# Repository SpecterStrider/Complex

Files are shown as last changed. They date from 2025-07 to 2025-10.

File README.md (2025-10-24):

# Project COMPLEX
Complex is a 36-key ergonomic split keyboard inspired by  

Corne by foostan and  
https://github.com/foostan/crkbd/tree/main

Tempest by thrly  
https://github.com/thrly/tempest

## TO DO List
- [ ] Impedance match USB
- [ ] Right Side PCB
- [ ] include Case and 3d files
- [ ] Rebase from kiCAD to Fusion ECAD
- [ ] Begin QMK firmware
- [ ] define COMPLEX.cpp in QMK environment
- [ ] create Keyamp

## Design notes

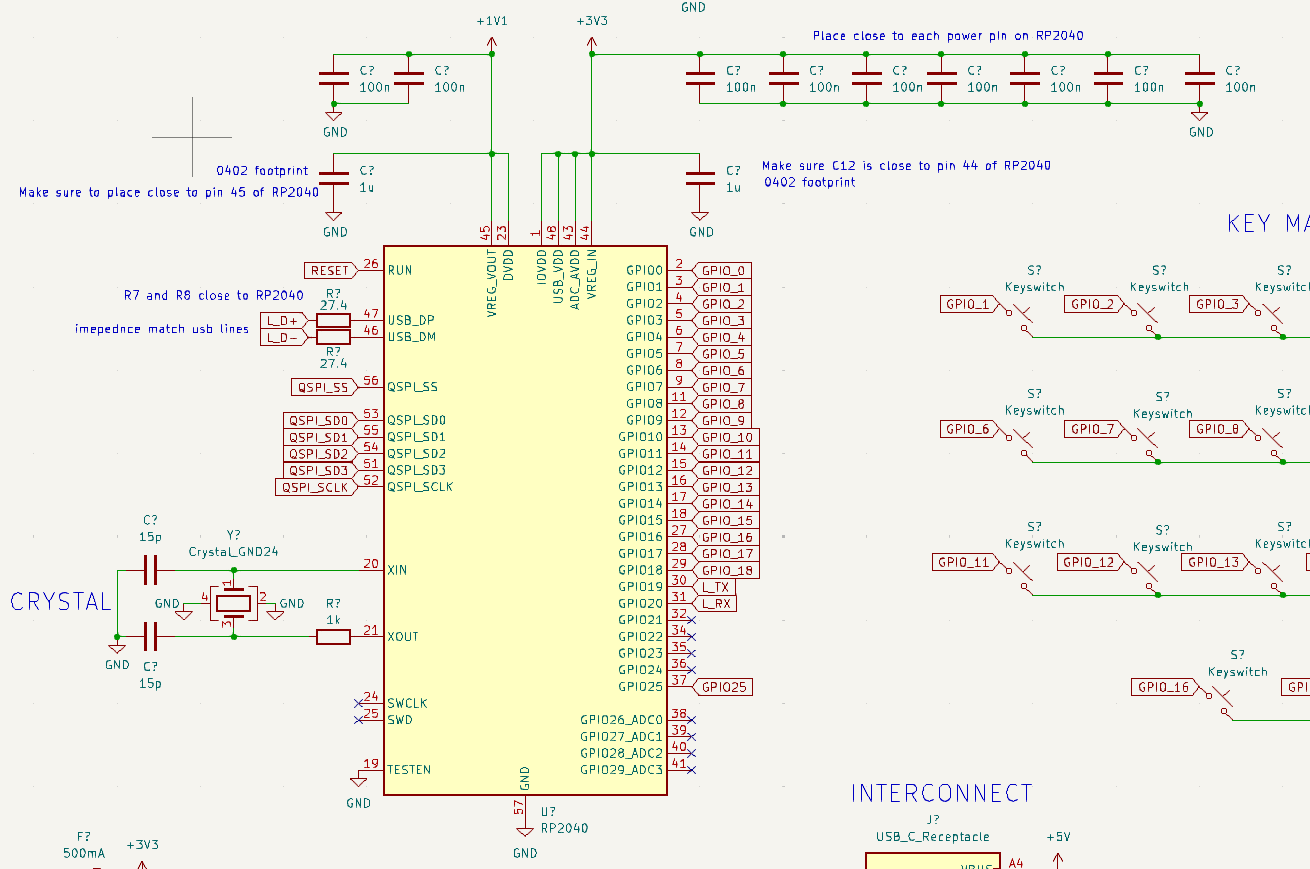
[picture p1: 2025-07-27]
Docs/MCU.png

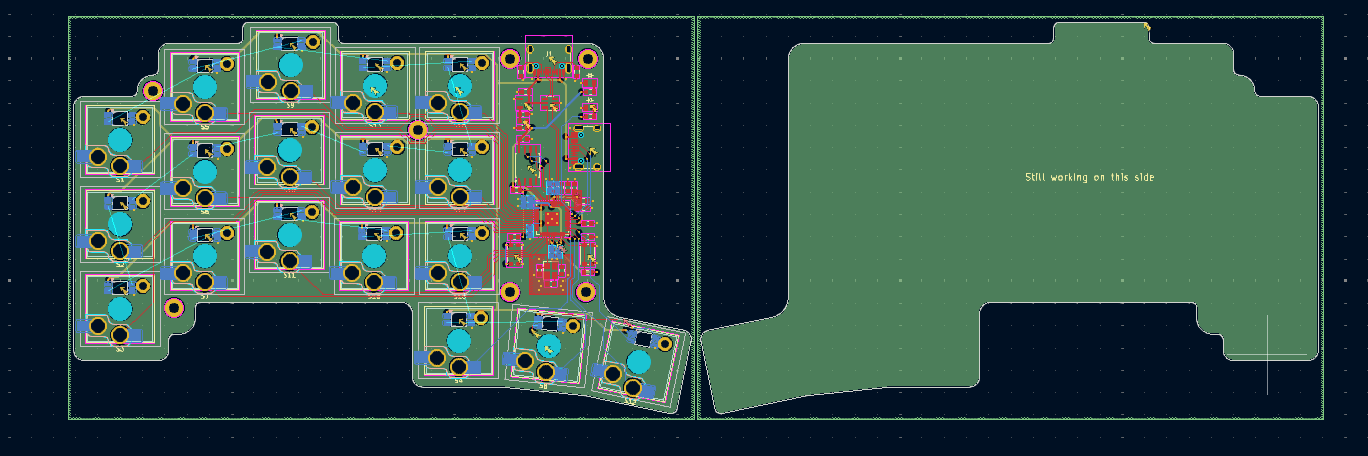
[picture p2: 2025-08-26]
Docs/PCB.png

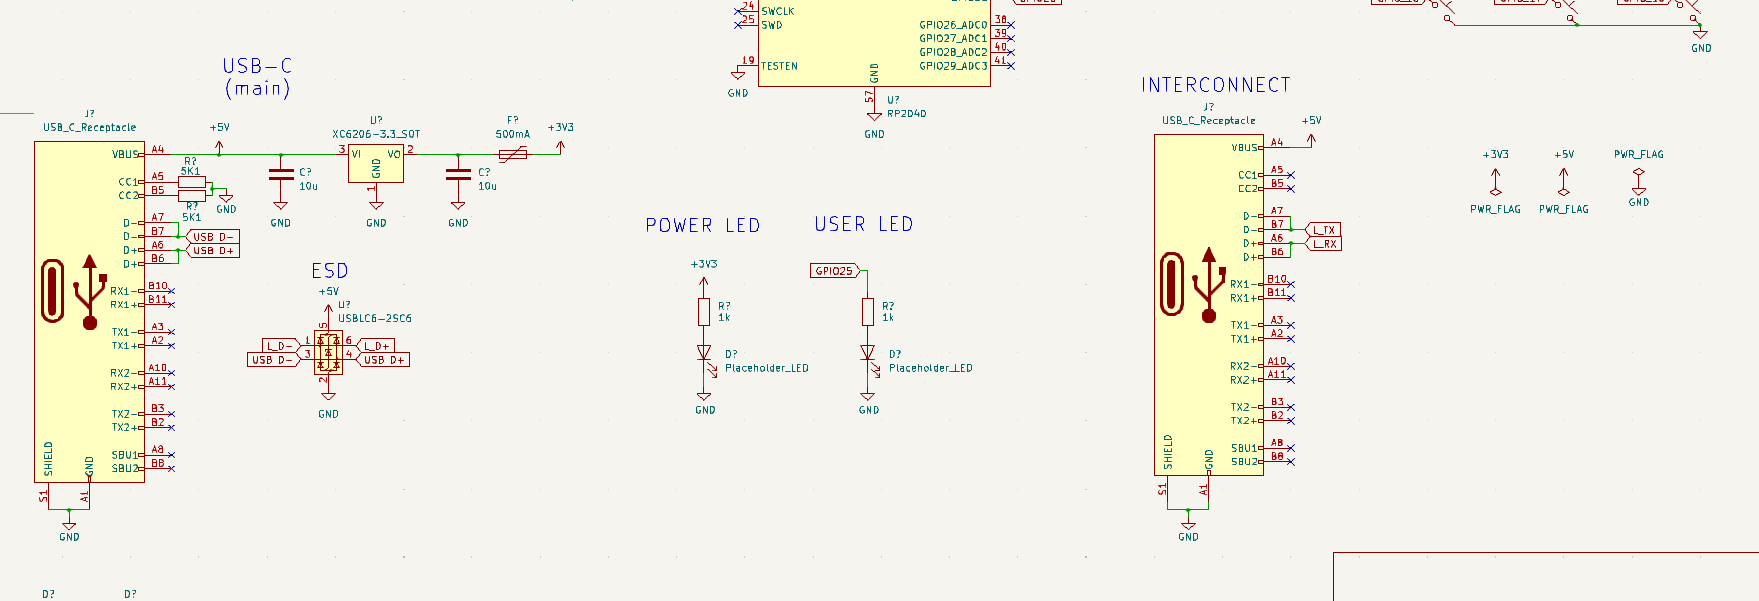
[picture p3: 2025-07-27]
Docs/lower.png

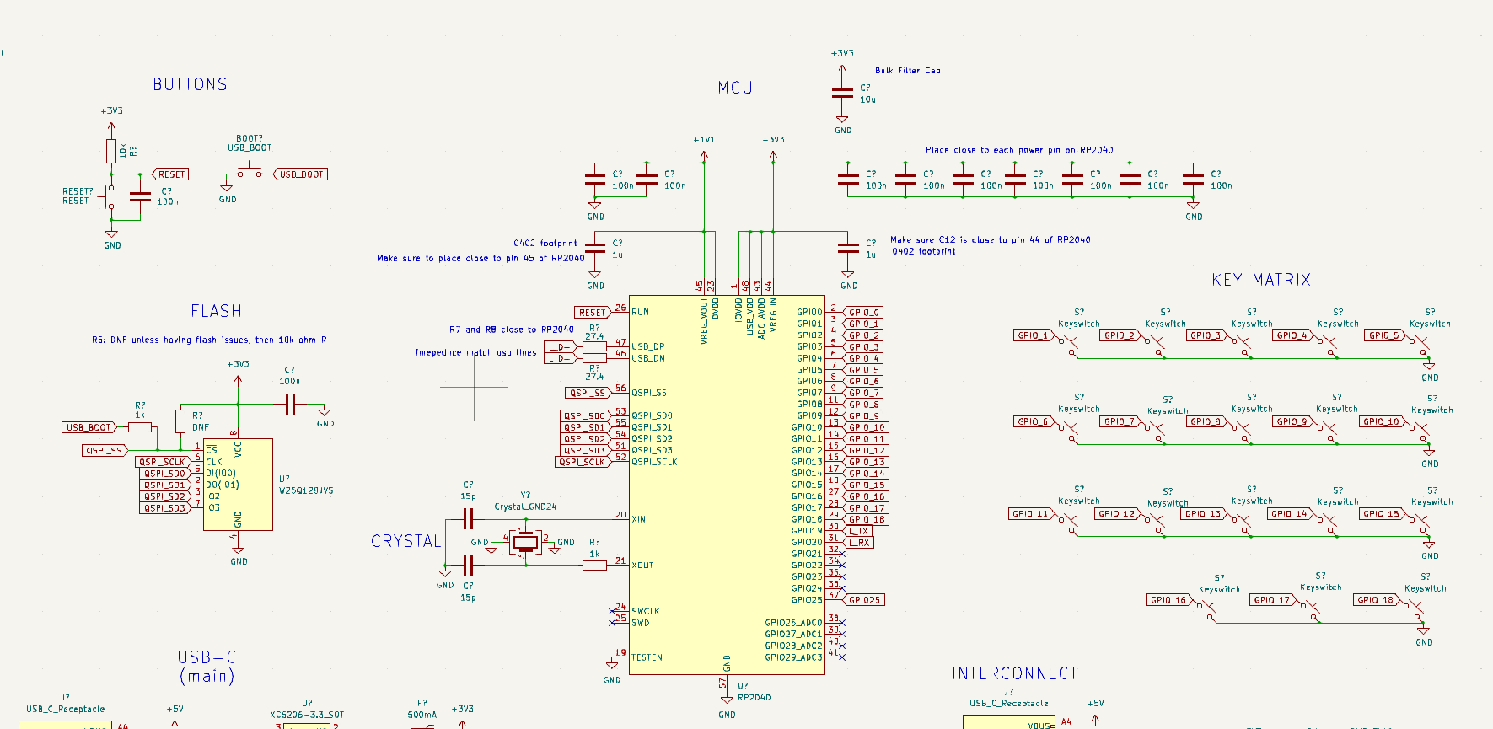
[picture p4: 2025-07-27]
Docs/Upper.png

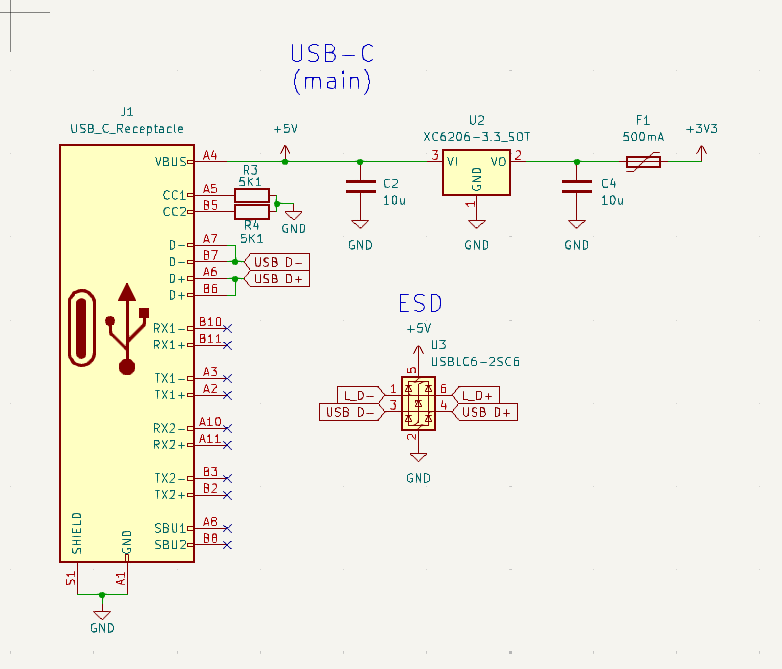
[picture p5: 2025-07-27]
Docs/USB C sch.png

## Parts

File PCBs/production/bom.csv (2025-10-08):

Designator | Footprint | Quantity | Value | LCSC Part #
_3, _2, |  | 3
BOOT1, BOOT2 | SW_Push_1P1T_NO_CK_KMR2 | 2 | USB_BOOT
C1, C11, C13, C14, C15, C16, C17, C18, C19, C21, C25, C27, C29, C3, C31, C32, C33, C34, C35, C36, C37, C38, C7, C9 | 0603 | 24 | 100n
C10, C2, C20, C22, C28, C4 | 0603 | 6 | 10u
C12, C26, C30, C8 | 0603 | 4 | 1u
C23, C24, C5, C6 | 0603 | 4 | 15p
D1, D10, D11, D12, D13, D14, D15, D16, D17, D18, D2, D23, D24, D25, D26, D27, D28, D29, D3, D30, D31, D32, D33, D34, D35, D36, D37, D38, D39, D4, D40, D5, D6, D7, D8, D9 | LED_SK6812MINI | 36 | LED_SK6812MINI | C5149201
D19, D20, D41, D42 | LED_0805 | 4 | Placeholder_LED
F1, F2 | Fuse_0603 | 2 | 500mA
J1, J3, J4, J6 | USB_C_Receptacle_HRO_TYPE-C-31-M-12 | 4 | USB_C_Receptacle
R1, R12 | 0603 | 2 | 10k
R10, R11, R16, R17, R2, R20, R6, R9 | 0603 | 8 | 1k
R13, R5 | 0603 | 2 | DNF
R14, R15, R3, R4 | 0603 | 4 | 5K1
R18, R19, R7, R8 | 0603 | 4 | 27.4
RESET1, RESET2 | SW_Push_1P1T_NO_CK_KMR2 | 2 | RESET
S1, S10, S11, S12, S13, S14, S15, S16, S17, S18, S19, S2, S20, S21, S22, S23, S24, S25, S26, S27, S28, S29, S3, S30, S31, S32, S33, S34, S35, S36, S4, S5, S6, S7, S8, S9 | Hotswap_Choc_V2_Plated_1.00u | 36 | Keyswitch
U1, U5 | SOIC-8_5.23x5.23mm_P1.27mm | 2 | W25Q128JVS
U2, U6 | Voltage_SOT-23 | 2 | XC6206-3.3_SOT
U3, U7 | SOT-23-6 | 2 | USBLC6-2SC6
U4, U8 | QFN-56-1EP_7x7mm_P0.4mm_EP3.2x3.2mm | 2 | RP2040
Y1, Y2 | Crystal_SMD_Abracon_ABM8G-4Pin_3.2x2.5mm | 2 | Crystal_GND24

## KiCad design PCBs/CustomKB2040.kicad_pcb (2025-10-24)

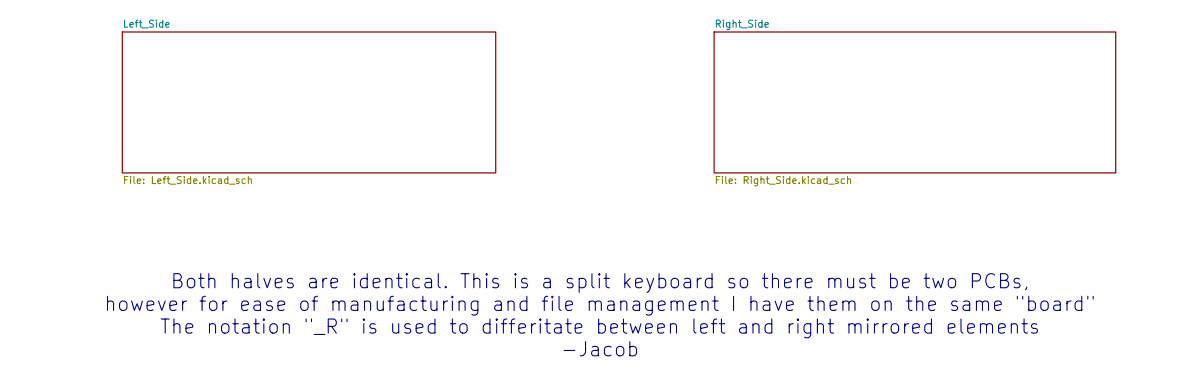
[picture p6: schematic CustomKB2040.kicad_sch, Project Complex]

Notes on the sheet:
Both halves are identical. This is a split keyboard so there must be two PCBs, however for ease of manufacturing and file management I have them on the same "board" The notation "_R" is used to differitate between left and right mirrored elements -Jacob

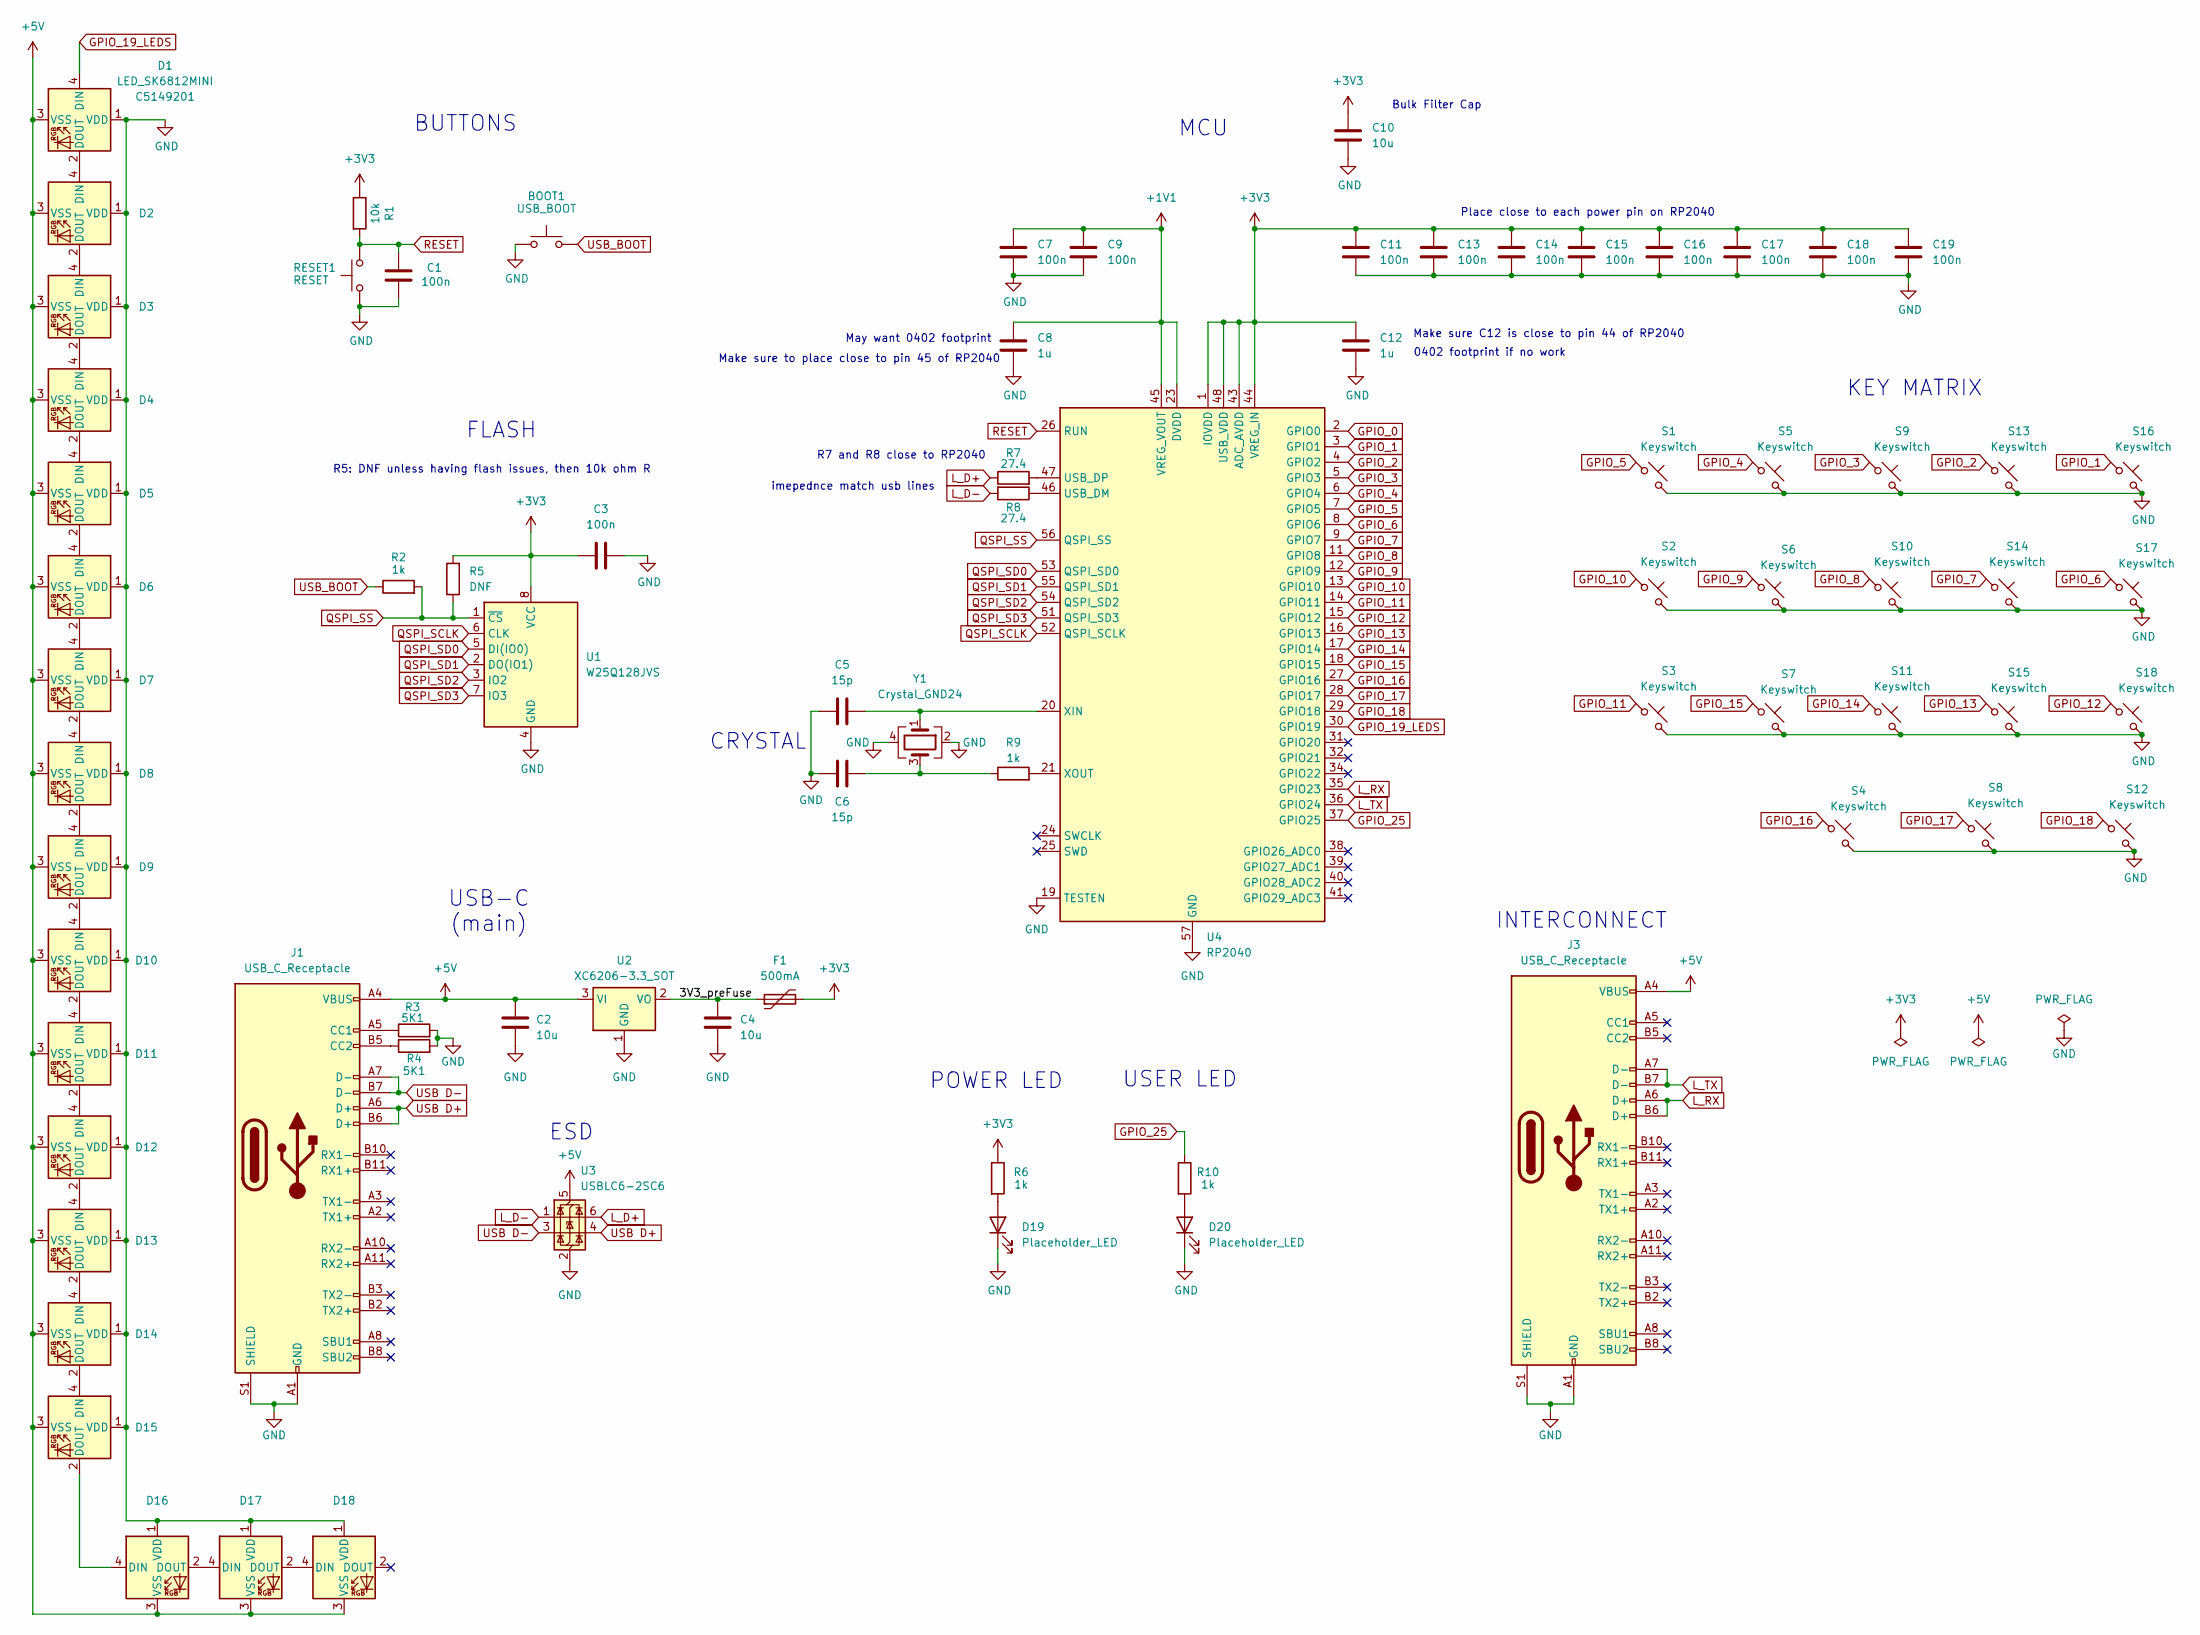
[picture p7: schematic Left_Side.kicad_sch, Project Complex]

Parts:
BOOT1: USB_BOOT; SW_Push_1P1T_NO_CK_KMR2
C1, C3, C7, C9, C11, C13, C14, C15, C16, C17, C18, C19: 100n; C_0603_1608Metric
C2, C4, C10: 10u; C_0603_1608Metric
C5, C6: 15p; C_0603_1608Metric
C8, C12: 1u; C_0603_1608Metric
D1, D2, D3, D4, D5, D6, D7, D8, D9, D10, D11, D12, D13, D14, D15, D16, D17, D18: LED_SK6812MINI; LCSC C5149201
D19, D20: Placeholder_LED; LED_0805
F1: 500mA; Fuse_0603
J1, J3: USB_C_Receptacle; USB_C_Receptacle_HRO_TYPE-C-31-M-12
R1: 10k; R_0603_1608Metric
R2, R6, R9, R10: 1k; R_0603_1608Metric
R3, R4: 5K1; R_0603_1608Metric
R5: DNF; R_0603_1608Metric
R7, R8: 27.4; R_0603_1608Metric
RESET1: RESET; SW_Push_1P1T_NO_CK_KMR2
S1, S2, S3, S4, S5, S6, S7, S8, S9, S10, S11, S12, S13, S14, S15, S16, S17, S18: Keyswitch; Hotswap_Choc_V2_Plated_1.00u
U1: W25Q128JVS; SOIC-8_5.23x5.23mm_P1.27mm
U2: XC6206-3.3_SOT; Voltage_SOT-23
U3: USBLC6-2SC6; SOT-23-6
U4: RP2040; QFN-56-1EP_7x7mm_P0.4mm_EP3.2x3.2mm
Y1: Crystal_GND24; Crystal_SMD_Abracon_ABM8G-4Pin_3.2x2.5mm

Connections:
+1V1: C7.1, C8.1, C9.1, U4.23 (DVDD), U4.45 (VREG_VOUT), U4.50 (DVDD)
+3V3: C3.1, C10.1, C11.1, C12.1, C13.1, C14.1, C15.1, C16.1, C17.1, C18.1, C19.1, F1.2, R1.1, R5.2, R6.1, U1.8 (VCC), U4.1 (IOVDD), U4.10 (IOVDD), U4.22 (IOVDD), U4.33 (IOVDD), U4.42 (IOVDD), U4.43 (ADC_AVDD), U4.44 (VREG_IN), U4.48 (USB_VDD), U4.49 (IOVDD)
+5V: C2.1, D1.3 (VSS), D2.3 (VSS), D3.3 (VSS), D4.3 (VSS), D5.3 (VSS), D6.3 (VSS), D7.3 (VSS), D8.3 (VSS), D9.3 (VSS), D10.3 (VSS), D11.3 (VSS), D12.3 (VSS), D13.3 (VSS), D14.3 (VSS), D15.3 (VSS), D16.3 (VSS), D17.3 (VSS), D18.3 (VSS), J1.A4 (VBUS), J1.A9 (VBUS), J1.B4 (VBUS), J1.B9 (VBUS), J3.A4 (VBUS), J3.A9 (VBUS), J3.B4 (VBUS), J3.B9 (VBUS), U2.3 (VI), U3.5 (VBUS)
/Left_Side/3V3_preFuse: C4.1, F1.1, U2.2 (VO)
GND: BOOT1.1, C1.1, C2.2, C3.2, C4.2, C5.2, C6.2, C7.2, C8.2, C9.2, C10.2, C11.2, C12.2, C13.2, C14.2, C15.2, C16.2, C17.2, C18.2, C19.2, D1.1 (VDD), D2.1 (VDD), D3.1 (VDD), D4.1 (VDD), D5.1 (VDD), D6.1 (VDD), D7.1 (VDD), D8.1 (VDD), D9.1 (VDD), D10.1 (VDD), D11.1 (VDD), D12.1 (VDD), D13.1 (VDD), D14.1 (VDD), D15.1 (VDD), D16.1 (VDD), D17.1 (VDD), D18.1 (VDD), D19.1 (K), D20.1 (K), J1.A1 (GND), J1.A12 (GND), J1.B1 (GND), J1.B12 (GND), J1.S1 (SHIELD), J3.A1 (GND), J3.A12 (GND), J3.B1 (GND), J3.B12 (GND), J3.S1 (SHIELD), R3.2, R4.2, RESET1.1, S1.2, S2.2, S3.2, S4.2, S5.2, S6.2, S7.2, S8.2, S9.2, S10.2, S11.2, S12.2, S13.2, S14.2, S15.2, S16.2, S17.2, S18.2, U1.4 (GND), U2.1 (GND), U3.2 (GND), U4.19 (TESTEN), U4.57 (GND), Y1.2, Y1.4
GPIO_0: U4.2 (GPIO0)
GPIO_1: S16.1, U4.3 (GPIO1)
GPIO_2: S13.1, U4.4 (GPIO2)
GPIO_3: S9.1, U4.5 (GPIO3)
GPIO_4: S5.1, U4.6 (GPIO4)
GPIO_5: S1.1, U4.7 (GPIO5)
GPIO_6: S17.1, U4.8 (GPIO6)
GPIO_7: S14.1, U4.9 (GPIO7)
GPIO_8: S10.1, U4.11 (GPIO8)
GPIO_9: S6.1, U4.12 (GPIO9)
GPIO_10: S2.1, U4.13 (GPIO10)
GPIO_11: S3.1, U4.14 (GPIO11)
GPIO_12: S18.1, U4.15 (GPIO12)
GPIO_13: S15.1, U4.16 (GPIO13)
GPIO_14: S11.1, U4.17 (GPIO14)
GPIO_15: S7.1, U4.18 (GPIO15)
GPIO_16: S4.1, U4.27 (GPIO16)
GPIO_17: S8.1, U4.28 (GPIO17)
GPIO_18: S12.1, U4.29 (GPIO18)
GPIO_19_LEDS: D1.4 (DIN), U4.30 (GPIO19)
GPIO_25: R10.1, U4.37 (GPIO25)
L_D+: R7.1, U3.6 (I/O1)
L_D-: R8.2, U3.1 (I/O1)
L_RX: J3.A6 (D+), J3.B6 (D+), U4.35 (GPIO23)
L_TX: J3.A7 (D-), J3.B7 (D-), U4.36 (GPIO24)
unnamed: C6.1, R9.1, Y1.3
unnamed: D1.2 (DOUT), D2.4 (DIN)
unnamed: D2.2 (DOUT), D3.4 (DIN)
unnamed: D3.2 (DOUT), D4.4 (DIN)
unnamed: D4.2 (DOUT), D5.4 (DIN)
unnamed: D5.2 (DOUT), D6.4 (DIN)
unnamed: D6.2 (DOUT), D7.4 (DIN)
unnamed: D7.2 (DOUT), D8.4 (DIN)
unnamed: D8.2 (DOUT), D9.4 (DIN)
unnamed: D9.2 (DOUT), D10.4 (DIN)
unnamed: D10.2 (DOUT), D11.4 (DIN)
unnamed: D11.2 (DOUT), D12.4 (DIN)
unnamed: D12.2 (DOUT), D13.4 (DIN)
unnamed: D13.2 (DOUT), D14.4 (DIN)
unnamed: D14.2 (DOUT), D15.4 (DIN)
unnamed: D15.2 (DOUT), D16.4 (DIN)
unnamed: D16.2 (DOUT), D17.4 (DIN)
unnamed: D17.2 (DOUT), D18.4 (DIN)
unnamed: D19.2 (A), R6.2
unnamed: D20.2 (A), R10.2
unnamed: J1.A5 (CC1), R3.1
unnamed: J1.B5 (CC2), R4.1
unnamed: R8.1, U4.46 (USB_DM)
unnamed: R7.2, U4.47 (USB_DP)
unnamed: C5.1, U4.20 (XIN), Y1.1
unnamed: R9.2, U4.21 (XOUT)
QSPI_SCLK: U1.6 (CLK), U4.52 (QSPI_SCLK)
QSPI_SD0: U1.5 (DI(IO0)), U4.53 (QSPI_SD0)
QSPI_SD1: U1.2 (DO(IO1)), U4.55 (QSPI_SD1)
QSPI_SD2: U1.3 (IO2), U4.54 (QSPI_SD2)
QSPI_SD3: U1.7 (IO3), U4.51 (QSPI_SD3)
QSPI_SS: R2.2, R5.1, U1.1 (~CS), U4.56 (QSPI_SS)
RESET: C1.2, R1.2, RESET1.2, U4.26 (RUN)
USB D+: J1.A6 (D+), J1.B6 (D+), U3.4 (I/O2)
USB D-: J1.A7 (D-), J1.B7 (D-), U3.3 (I/O2)
USB_BOOT: BOOT1.2, R2.1

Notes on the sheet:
MCU
Bulk Filter Cap
Make sure C12 is close to pin 44 of RP2040
USER LED
POWER LED
FLASH
ESD
R7 and R8 close to RP2040
CRYSTAL
May want 0402 footprint
INTERCONNECT
BUTTONS
Make sure to place close to pin 45 of RP2040
R5: DNF unless having flash issues, then 10k ohm R
imepednce match usb lines
USB-C (main)
0402 footprint if no work
Place close to each power pin on RP2040
KEY MATRIX

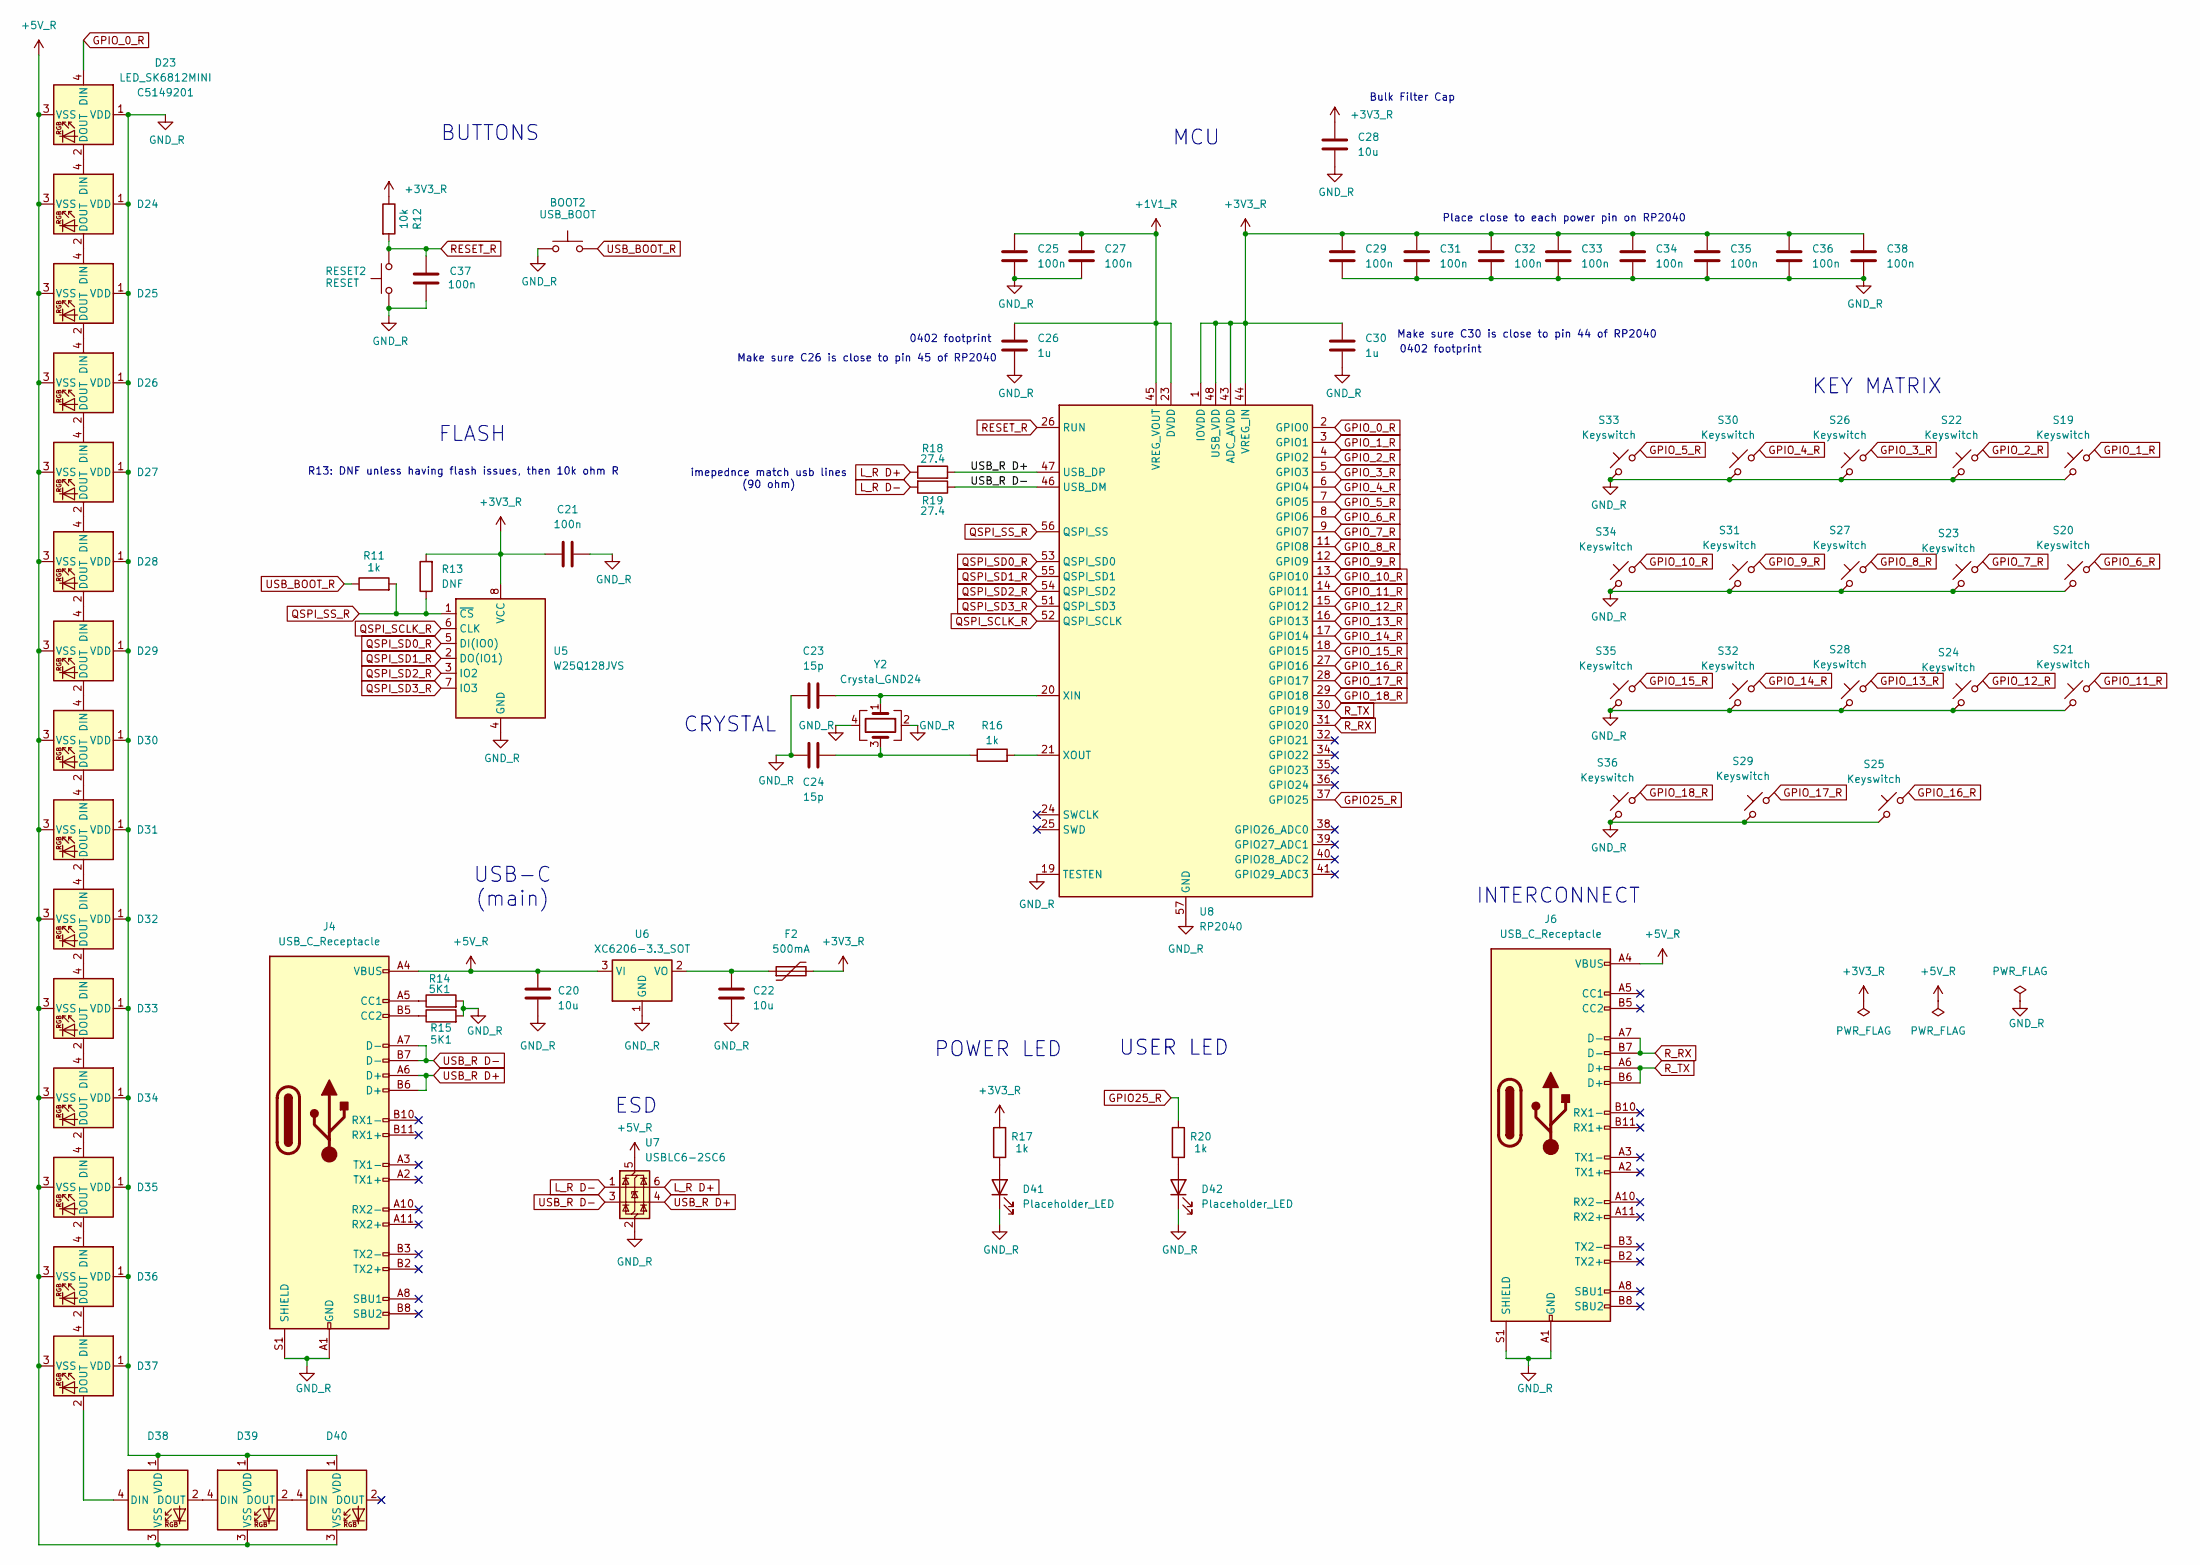
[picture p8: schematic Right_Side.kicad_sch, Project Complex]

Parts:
BOOT2: USB_BOOT; SW_Push_1P1T_NO_CK_KMR2
C20, C22, C28: 10u; C_0603_1608Metric
C21, C25, C27, C29, C31, C32, C33, C34, C35, C36, C37, C38: 100n; C_0603_1608Metric
C23, C24: 15p; C_0603_1608Metric
C26, C30: 1u; C_0603_1608Metric
D23, D24, D25, D26, D27, D28, D29, D30, D31, D32, D33, D34, D35, D36, D37, D38, D39, D40: LED_SK6812MINI; LCSC C5149201
D41, D42: Placeholder_LED; LED_0805
F2: 500mA; Fuse_0603
J4, J6: USB_C_Receptacle; USB_C_Receptacle_HRO_TYPE-C-31-M-12
R11, R16, R17, R20: 1k; R_0603_1608Metric
R12: 10k; R_0603_1608Metric
R13: DNF; R_0603_1608Metric
R14, R15: 5K1; R_0603_1608Metric
R18, R19: 27.4; R_0603_1608Metric
RESET2: RESET; SW_Push_1P1T_NO_CK_KMR2
S19, S20, S21, S22, S23, S24, S25, S26, S27, S28, S29, S30, S31, S32, S33, S34, S35, S36: Keyswitch; Hotswap_Choc_V2_Plated_1.00u
U5: W25Q128JVS; SOIC-8_5.23x5.23mm_P1.27mm
U6: XC6206-3.3_SOT; Voltage_SOT-23
U7: USBLC6-2SC6; SOT-23-6
U8: RP2040; QFN-56-1EP_7x7mm_P0.4mm_EP3.2x3.2mm
Y2: Crystal_GND24; Crystal_SMD_Abracon_ABM8G-4Pin_3.2x2.5mm

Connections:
+1V1_R: C25.1, C26.1, C27.1, U8.23 (DVDD), U8.45 (VREG_VOUT), U8.50 (DVDD)
+3V3_R: C21.1, C28.1, C29.1, C30.1, C31.1, C32.1, C33.1, C34.1, C35.1, C36.1, C38.1, F2.2, R12.1, R13.2, R17.1, U5.8 (VCC), U8.1 (IOVDD), U8.10 (IOVDD), U8.22 (IOVDD), U8.33 (IOVDD), U8.42 (IOVDD), U8.43 (ADC_AVDD), U8.44 (VREG_IN), U8.48 (USB_VDD), U8.49 (IOVDD)
+5V_R: C20.1, D23.3 (VSS), D24.3 (VSS), D25.3 (VSS), D26.3 (VSS), D27.3 (VSS), D28.3 (VSS), D29.3 (VSS), D30.3 (VSS), D31.3 (VSS), D32.3 (VSS), D33.3 (VSS), D34.3 (VSS), D35.3 (VSS), D36.3 (VSS), D37.3 (VSS), D38.3 (VSS), D39.3 (VSS), D40.3 (VSS), J4.A4 (VBUS), J4.A9 (VBUS), J4.B4 (VBUS), J4.B9 (VBUS), J6.A4 (VBUS), J6.A9 (VBUS), J6.B4 (VBUS), J6.B9 (VBUS), U6.3 (VI), U7.5 (VBUS)
GND_R: BOOT2.1, C20.2, C21.2, C22.2, C23.2, C24.2, C25.2, C26.2, C27.2, C28.2, C29.2, C30.2, C31.2, C32.2, C33.2, C34.2, C35.2, C36.2, C37.1, C38.2, D23.1 (VDD), D24.1 (VDD), D25.1 (VDD), D26.1 (VDD), D27.1 (VDD), D28.1 (VDD), D29.1 (VDD), D30.1 (VDD), D31.1 (VDD), D32.1 (VDD), D33.1 (VDD), D34.1 (VDD), D35.1 (VDD), D36.1 (VDD), D37.1 (VDD), D38.1 (VDD), D39.1 (VDD), D40.1 (VDD), D41.1 (K), D42.1 (K), J4.A1 (GND), J4.A12 (GND), J4.B1 (GND), J4.B12 (GND), J4.S1 (SHIELD), J6.A1 (GND), J6.A12 (GND), J6.B1 (GND), J6.B12 (GND), J6.S1 (SHIELD), R14.2, R15.2, RESET2.1, S19.2, S20.2, S21.2, S22.2, S23.2, S24.2, S25.2, S26.2, S27.2, S28.2, S29.2, S30.2, S31.2, S32.2, S33.2, S34.2, S35.2, S36.2, U5.4 (GND), U6.1 (GND), U7.2 (GND), U8.19 (TESTEN), U8.57 (GND), Y2.2, Y2.4
GPIO25_R: R20.1, U8.37 (GPIO25)
GPIO_0_R: D23.4 (DIN), U8.2 (GPIO0)
GPIO_1_R: S19.1, U8.3 (GPIO1)
GPIO_2_R: S22.1, U8.4 (GPIO2)
GPIO_3_R: S26.1, U8.5 (GPIO3)
GPIO_4_R: S30.1, U8.6 (GPIO4)
GPIO_5_R: S33.1, U8.7 (GPIO5)
GPIO_6_R: S20.1, U8.8 (GPIO6)
GPIO_7_R: S23.1, U8.9 (GPIO7)
GPIO_8_R: S27.1, U8.11 (GPIO8)
GPIO_9_R: S31.1, U8.12 (GPIO9)
GPIO_10_R: S34.1, U8.13 (GPIO10)
GPIO_11_R: S21.1, U8.14 (GPIO11)
GPIO_12_R: S24.1, U8.15 (GPIO12)
GPIO_13_R: S28.1, U8.16 (GPIO13)
GPIO_14_R: S32.1, U8.17 (GPIO14)
GPIO_15_R: S35.1, U8.18 (GPIO15)
GPIO_16_R: S25.1, U8.27 (GPIO16)
GPIO_17_R: S29.1, U8.28 (GPIO17)
GPIO_18_R: S36.1, U8.29 (GPIO18)
L_R D+: R18.1, U7.6 (I/O1)
L_R D-: R19.2, U7.1 (I/O1)
unnamed: C24.1, R16.1, Y2.3
unnamed: D23.2 (DOUT), D24.4 (DIN)
unnamed: D24.2 (DOUT), D25.4 (DIN)
unnamed: D25.2 (DOUT), D26.4 (DIN)
unnamed: D26.2 (DOUT), D27.4 (DIN)
unnamed: D27.2 (DOUT), D28.4 (DIN)
unnamed: D28.2 (DOUT), D29.4 (DIN)
unnamed: D29.2 (DOUT), D30.4 (DIN)
unnamed: D30.2 (DOUT), D31.4 (DIN)
unnamed: D31.2 (DOUT), D32.4 (DIN)
unnamed: D32.2 (DOUT), D33.4 (DIN)
unnamed: D33.2 (DOUT), D34.4 (DIN)
unnamed: D34.2 (DOUT), D35.4 (DIN)
unnamed: D35.2 (DOUT), D36.4 (DIN)
unnamed: D36.2 (DOUT), D37.4 (DIN)
unnamed: D37.2 (DOUT), D38.4 (DIN)
unnamed: D38.2 (DOUT), D39.4 (DIN)
unnamed: D39.2 (DOUT), D40.4 (DIN)
unnamed: D41.2 (A), R17.2
unnamed: D42.2 (A), R20.2
unnamed: J4.A5 (CC1), R14.1
unnamed: J4.B5 (CC2), R15.1
unnamed: C22.1, F2.1, U6.2 (VO)
unnamed: C23.1, U8.20 (XIN), Y2.1
unnamed: R16.2, U8.21 (XOUT)
QSPI_SCLK_R: U5.6 (CLK), U8.52 (QSPI_SCLK)
QSPI_SD0_R: U5.5 (DI(IO0)), U8.53 (QSPI_SD0)
QSPI_SD1_R: U5.2 (DO(IO1)), U8.55 (QSPI_SD1)
QSPI_SD2_R: U5.3 (IO2), U8.54 (QSPI_SD2)
QSPI_SD3_R: U5.7 (IO3), U8.51 (QSPI_SD3)
QSPI_SS_R: R11.2, R13.1, U5.1 (~CS), U8.56 (QSPI_SS)
RESET_R: C37.2, R12.2, RESET2.2, U8.26 (RUN)
R_RX: J6.A7 (D-), J6.B7 (D-), U8.31 (GPIO20)
R_TX: J6.A6 (D+), J6.B6 (D+), U8.30 (GPIO19)
USB_BOOT_R: BOOT2.2, R11.1
USB_R D+: J4.A6 (D+), J4.B6 (D+), R18.2, U7.4 (I/O2), U8.47 (USB_DP)
USB_R D-: J4.A7 (D-), J4.B7 (D-), R19.1, U7.3 (I/O2), U8.46 (USB_DM)

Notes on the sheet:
Make sure C30 is close to pin 44 of RP2040
0402 footprint
CRYSTAL
R13: DNF unless having flash issues, then 10k ohm R
MCU
KEY MATRIX
imepednce match usb lines (90 ohm)
POWER LED
Bulk Filter Cap
ESD
Place close to each power pin on RP2040
USB-C (main)
INTERCONNECT
USER LED
FLASH
Make sure C26 is close to pin 45 of RP2040
BUTTONS

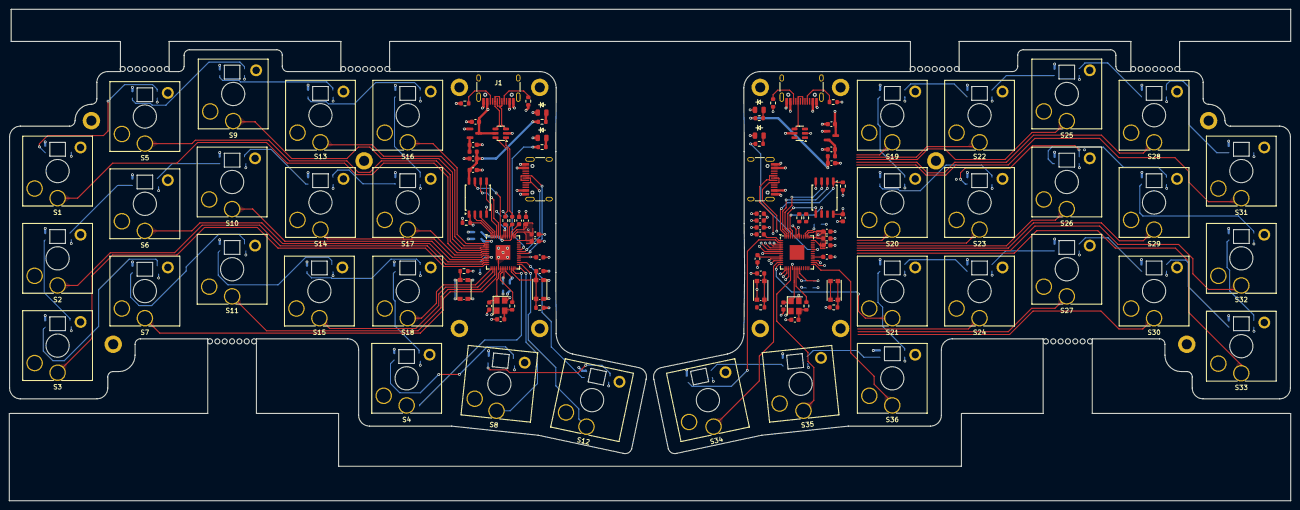
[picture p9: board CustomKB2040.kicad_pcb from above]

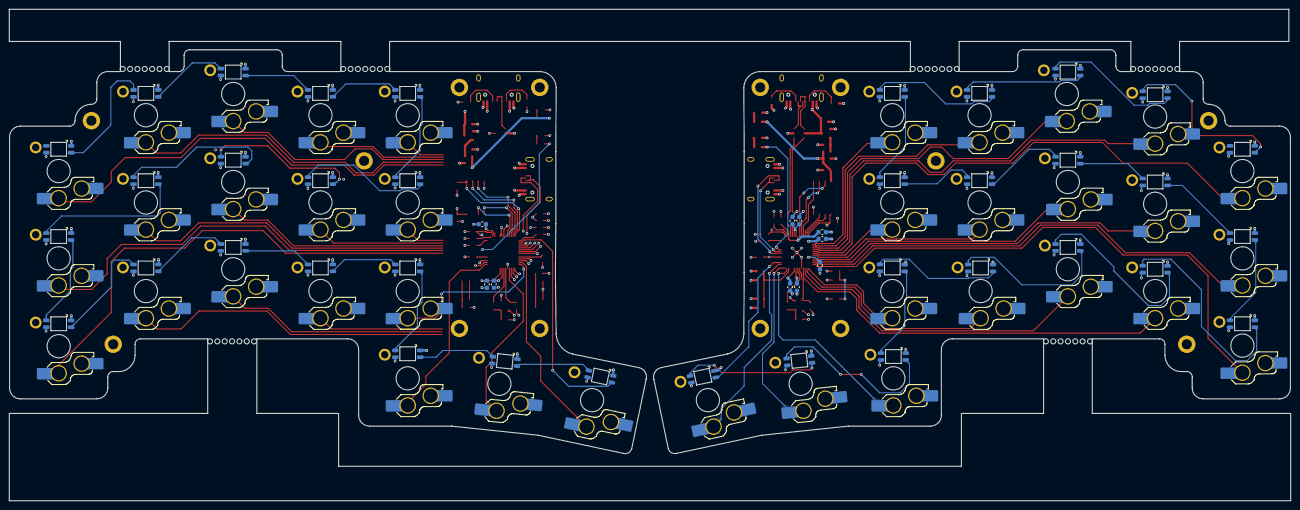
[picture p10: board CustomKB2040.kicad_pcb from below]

Board: 4 copper layers, 279.0 x 107.0 mm, 154 parts (46 on the bottom side), 128 nets.

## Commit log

2025-08-06 placed companets and semi routed
    [CustomKB2040.kicad_pcb, Left_Side.kicad_sch, Right_Side.kicad_sch]
2025-08-13 added 5v pads
    [CustomKB2040.kicad_pcb, Left_Side.kicad_sch, Right_Side.kicad_sch]
2025-08-13 why is this not working
    [CustomKB2040.kicad_pcb]
2025-08-25 converted to 4 layer board
    [CustomKB2040.kicad_pcb, Left_Side.kicad_sch, Right_Side.kicad_sch]
2025-08-26 Finished left side
    [CustomKB2040.kicad_pcb, Left_Side.kicad_sch, Right_Side.kicad_sch]
2025-08-26 added PCB image
2025-08-26 resturctured repo
    [CustomKB2040.kicad_pcb, CustomKB2040.kicad_sch, Left_Side.kicad_sch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]
2025-09-26 began right side
    [CustomKB2040.kicad_pcb]
2025-09-26 store for replacement
    [CustomKB2040.kicad_pcb]
2025-09-29 near complete right side
    [CustomKB2040.kicad_pcb, CustomKB2040.kicad_sch, Left_Side.kicad_sch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]
2025-10-05 mid way right side
    [CustomKB2040.kicad_pcb, CustomKB2040.kicad_sch, Right_Side.kicad_sch]
2025-10-08 edge outline done
    [CustomKB2040.kicad_pcb, bom.csv, designators.csv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]
2025-10-24 making progress
    [CustomKB2040.kicad_pcb, Right_Side.kicad_sch]
2025-10-24 Update TO DO list to include Case and 3D files
